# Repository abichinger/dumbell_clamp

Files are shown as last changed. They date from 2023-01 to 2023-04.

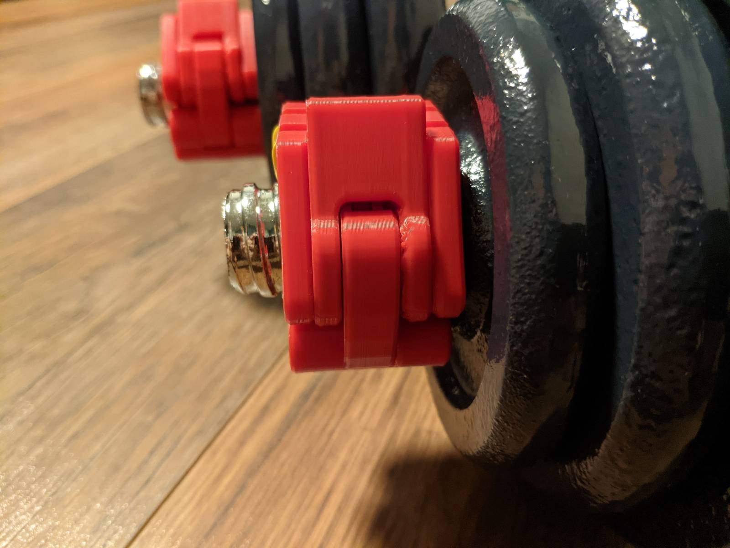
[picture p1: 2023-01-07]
assets/signal-2023-01-07-223349_003.jpeg

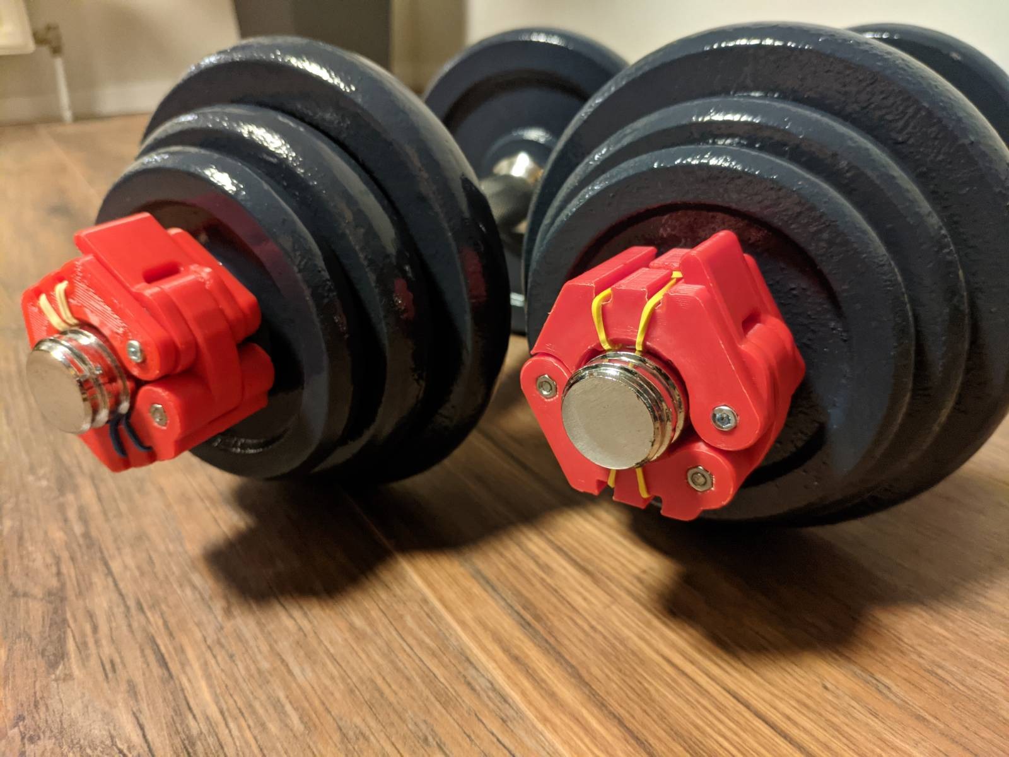
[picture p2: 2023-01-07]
assets/signal-2023-01-07-223349_005.jpeg

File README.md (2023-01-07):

**A customizable clamp to secure your weights on your dumbell or barbell.**

Choose between **25mm, 30mm, 50mm** or open up the Customizer and set a **custom diameter** with `Bar_Diameter`.
The grooves allow you to add **rubber bands** for optimal grip. If the clamp is too loose, you can add more rubber bands or increase the `Compression` parameter.

Required bolts (`Height` parameter set to 33mm):
- 2x M3x30mm
- 2x M3x8mm
- 1x M3x18mm
- 5x M3 hex nut

If you prefer to use pins, you can set the parameter `Hinge_Type` to `Pin`.

**Disclaimer**: I only printed the clamp with a diameter of 25mm. I hope the other versions work as well.

If you have some suggestion or need help, please open an issue at the [GitHub repository](https://github.com/abichinger/dumbell_clamp)

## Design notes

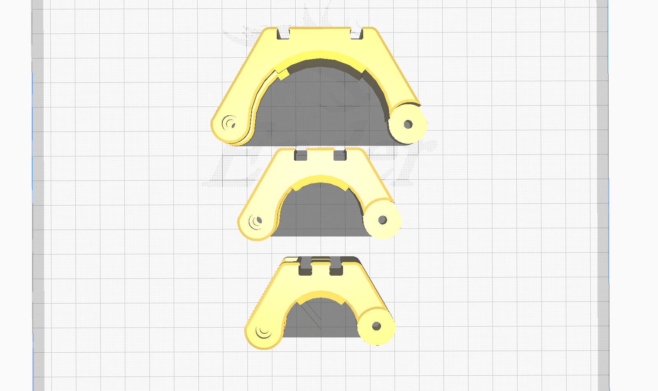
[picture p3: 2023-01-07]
assets/sizes.png

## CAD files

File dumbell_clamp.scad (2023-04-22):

Part_Selection = 0; // [0:Clamp, 1:Top, 2:Bottom, 3:Latch_Part1, 4:Latch_Part2, 5:None]
Bar_Diameter = 25;
Compression = 0.7;
Joint_Diameter = 15;
Bumper_Height = 1.5;
Bumper_Angle = 80;
Lever_Hole_Dist = 7.5;
Lever_Overhang = 9;

Height = 33;

Edge_Height = 1;
Edge_Radius = 7;

Bolt_Size = 0; // [0:M3, 1:M4, 2:M5]
Hinge_Type = 0; // [0:Bolt, 1:Pin]

Groove_Width = 5;
Groove_Height = 5;
Groove_Offset = -2;
Groove_Count = 1;

Grooves = true;
Bridges = false;
Cut_in_Half = false;
Second_Half = false;

/* [Hidden] */

od = Bar_Diameter+2*Joint_Diameter+2*Bumper_Height;
id = Bar_Diameter+2*Bumper_Height;
bar_d = Bar_Diameter - Compression;
bar_r = bar_d/2;
sub_h = Height/3;
alpha = (180-Bumper_Angle)/2;
joint_t = 0.8;
jd = Joint_Diameter + joint_t;
t = 0.25;
w = (od/2)*cos(30)*2;

Joint_Radius = Joint_Diameter/2;
jr = id/2+Joint_Radius;

//Kosinussatz https://de.wikipedia.org/wiki/Kosinussatz
function law_of_cos(a, b, gamma) = sqrt(a*a+b*b-2*a*b*cos(gamma));
function law_of_acos(a, b, c) = acos((a*a+b*b-c*c)/(2*a*b));
beta = law_of_acos(id/2+Joint_Radius, id/2+Joint_Radius, Joint_Diameter);
echo("beta", beta);

groove_dist = law_of_cos(bar_r, bar_r, Bumper_Angle);

$fn=30;

// Gewindedurchmesser, Schraubenkopfdurchmesser, Schraubenkopfhöhe
bolt_specs = [
    [3, 5.5, 3],
    [4, 7, 4],
    [5, 8.5, 5]
];
bolt_spec_t = [0.4, 0.7, 0.2];

// width across flats, thickness
nut_specs = [
    [5.5, 2.4],
    [7, 3.2],
    [8, 4.7]
];
nut_spec_t = [0.4, 0.3];

bolt_spec = bolt_specs[Bolt_Size];
nut_spec = nut_specs[Bolt_Size];

hinge_d = (Hinge_Type == 0) ? bolt_spec[0] + bolt_spec_t[0] : bolt_spec[0] + 0.1;
bolt_head_d = bolt_spec[1] + bolt_spec_t[1];
bolt_head_h = bolt_spec[2] + bolt_spec_t[2];
nut_w = nut_spec[0] + nut_spec_t[0];
nut_h = nut_spec[1] + nut_spec_t[1];

gamma = law_of_acos(id/2+Joint_Radius, id/2+Joint_Radius, Lever_Hole_Dist);
Latch_Angle = beta+gamma;

module hinge_base(Height=Height) {
    cylinder(d=hinge_d, h=Height);
}

//hinge_cut();

module hinge_cut(Height=Height) {

    layer_h = 0.2;

    if(Hinge_Type == 0) { //Bolt
        rotate(30)
        nut(nut_w, nut_h);

        if (Bridges) {
            hinge_h = Height-bolt_head_h-nut_h-2*layer_h;
            translate([0,0,nut_h+layer_h])
            hinge_base(hinge_h);
        }
        else {
            hinge_base();
        }

        translate([0,0,Height-bolt_head_h])
        cylinder(d=bolt_head_d, h=bolt_head_h);

        
    } else {
        hinge_base();
    }
}

module nut(w, h){
    $fn = 6;
    r = w/sqrt(3);
    cylinder(r=r, h=h);
}

module hexagon(d, h, e=Edge_Height) {
    r = d/2 - Edge_Radius/2;

    hull(){
        for(i = [0:5]){
            rotate([0,0,60*i])
            translate([r, 0])
            pillar(Edge_Radius, Edge_Radius-2*Edge_Height, h, Edge_Height);
        }
    }
}

//hexagon(od, Height);

module cone(d1, d2, h, angle=360) {
    r1 = d1/2;
    r2 = d2/2;
    
    rotate_extrude(angle=angle, convexity=10)
    polygon([
        [0,0],
        [r1, 0],
        [r2, h],
        [0, h]
    ]);
}

module rcube(size, e=-Edge_Height, r=Edge_Radius) {
    d = 2*r;
    s = [size[0]-d, size[1]-d, size[2]];

    translate([r,r])
    union(){
        long_pillar(d, d+2*e, s[2], abs(e), s[0]);
    
        translate([0, s[1]])
        long_pillar(d, d+2*e, s[2], abs(e), s[0]);
        
        rotate([-90,0,0])
        linear_extrude(s[1])
        projection()
        rotate([90,0,0])
        long_pillar(d, d+2*e, s[2], abs(e), s[0]);
    }
    
    
}

module pillar(d, base_d, h, base_h, angle=360) {
    cone(base_d, d, base_h, angle);
    translate([0, 0, base_h])
    cone(d, d, h-2*base_h, angle);
    translate([0, 0, h-base_h])
    cone(d, base_d, base_h, angle);
}

module long_pillar(d, base_d, h, base_h, l){
    
    pillar(d, base_d, h, base_h);
    translate([l,0])
    pillar(d, base_d, h, base_h);

    translate([l,0])
    rotate([0,-90,0])
    linear_extrude(l)
    projection()
    rotate([0,90,0])
    pillar(d, base_d, h, base_h);
    
}

function reverse(vec) = [for(i = [len(vec)-1:-1:0]) vec[i]];

function sum(vec, i=0) = vec[i] + 
    (i < len(vec)-1 ? sum(vec, i+1) : 0);

module pillar2(d, h, angle=360) {

    rh = reverse(h);

    for(i = [0:len(d)-2]) {
        z = (i > 0) ? sum(rh, len(rh)-i) : 0;
        translate([0, 0, z])
        cone(d[i], d[i+1], h[i], angle);
    }
}

module part_base(h) {

    difference(){
        union() {
            difference(){
                hexagon(od, h);

                translate([-od/2, -od/2, 0])
                cube([od, od/2, h]);
            }

            translate([id/2+Joint_Diameter/2,0])
            rotate([0,0,180])
            pillar(Joint_Diameter, Joint_Diameter-2*Edge_Height, h, Edge_Height, angle=180);

            translate([-id/2-Joint_Diameter/2,0])
            rotate([0,0,180])
            pillar(Joint_Diameter, Joint_Diameter-2*Edge_Height, h, Edge_Height, angle=180);
        }
        union() {
            pillar(id, id+2*Edge_Height, h, Edge_Height, angle=alpha+0.01);

            rotate([0,0,180-alpha])
            pillar(id, id+2*Edge_Height, h, Edge_Height, angle=alpha+0.01);

            rotate([0,0,alpha-1])
            pillar(bar_d, id+2*Edge_Height, h, 2*Edge_Height, angle=Bumper_Angle+2);
        }
    }
}

// part_base(Height);

module top() {

    module cut() {
        cone(od+10, od+10, Height, 90);
    }

    module cut2() {
        rotate(120)
        cone(od+10, od+10, Height, 180);
    }

    difference(){
        part_base(Height);
    
        translate([-id/2-Joint_Diameter/2, 0, sub_h-t])
        cylinder(d=jd, h=sub_h+2*t);

        rotate(-30)
        cut();

        cut2();

        rotate(beta)
        translate([id/2+Joint_Diameter/2, 0, sub_h])
        cylinder(d=jd, h=sub_h);
    }

    difference(){
        union(){
            rotate(beta)
            translate([id/2+Joint_Diameter/2,0])
            rotate([0,0,180])
            pillar(Joint_Diameter, Joint_Diameter-2*Edge_Height, Height, Edge_Height);

            intersection() {
                part_base(Height);
                
                rotate(beta)
                cone(od+10, od+10, Height, 60-beta);
            }
        }

        rotate(beta)
        translate([id/2+Joint_Diameter/2, 0, sub_h])
        cylinder(d=jd, h=sub_h);
    }

    intersection(){
        union(){
            part_base(sub_h-t);

            translate([0,0,Height-sub_h+t])
            part_base(sub_h-t);
        }
        
        cut2();
    }

}

module top_part() {
    difference(){
        top();
        
        translate([-jr, 0])
        hinge_cut();

        rotate(beta)
        translate([+jr, 0])
        rotate(-beta)
        hinge_cut();

        if (Grooves) {
            translate([0, w/2+0.5, 0])
            groove_cuts();
        }

        if (Cut_in_Half) {
            translate([0,0, Second_Half ? 0 : Height/2])
            cylinder(d=od+10,h=Height/2);
        }
    }
}

module bottom() {

    lever_w = (w-id)/2;

    module cut() {
        rotate(120)
        cone(od+10, od+10, Height, 180);
    }

    difference(){
        part_base(Height);

        translate([jr, 0, 0])
        pillar2([jd+2*Edge_Height, jd, jd], [Edge_Height, sub_h-Edge_Height]);

        translate([jr, 0, Height-sub_h])
        pillar2([jd, jd, jd+2*Edge_Height], [sub_h-Edge_Height, Edge_Height]);

        rotate(60)
        translate([-od/4,w/2-lever_w/2+Edge_Height,sub_h/2])
        lever(Height-sub_h, e=0);

        cut();
    }

    intersection(){
        union(){
            part_base(sub_h/2);

            translate([0,0,Height-sub_h/2])
            part_base(sub_h/2);
        }
        
        cut();
    }
}

module bottom_part() {
    difference() {
        bottom();

        translate([+jr, 0])
        hinge_cut();

        translate([-jr, 0])
        union() {
            cylinder(d=bolt_head_d, h=bolt_head_h);

            hinge_base();

            translate([0,0,Height-bolt_head_h])
            cylinder(d=bolt_head_d, h=bolt_head_h);
        }

        if (Grooves) {
            translate([0, w/2+0.5, 0])
            groove_cuts();
        }

        if (Cut_in_Half) {
            translate([0,0, Second_Half ? 0 : Height/2])
            cylinder(d=od+10,h=Height/2);
        }
    }
}

module _latch_part1() {

    h = sub_h-2*t;

    intersection(){
        difference(){
            pillar(od, od-2*Edge_Height, h, Edge_Height);
            pillar(id, id+2*Edge_Height, sub_h, Edge_Height);
        }
        
        cone(od+10, od+10, sub_h, Latch_Angle);
    }

    translate([jr,0])
    pillar(Joint_Diameter, Joint_Diameter-2*Edge_Height, h, Edge_Height);

    rotate(Latch_Angle)
    translate([jr,0])
    pillar(Joint_Diameter, Joint_Diameter-2*Edge_Height, h, Edge_Height);
}

module latch_part1() {
    difference(){
        _latch_part1();
        
        translate([jr,0,0])
        hinge_base();
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

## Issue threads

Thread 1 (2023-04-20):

Non-manifold

ABrambleNinja, 2023-04-20:
Hi,
Firstly, thanks so much for making this project! I really like the design and I'm very impressed you made it in OpenSCAD.

When I render this in OpenSCAD, it complains that it is not manifold, and when I import it into PrusaSlicer, some things that should not be filled in are filled in, like some of the bolt holes.

Do you have some process you use to transform the solid into something your slicer works on, or is your slicer just able to handle the volume?

I tried looking into changing the model to not have overlapping faces because I think that is what results in the non-manifold-ness but it's hard for me to understand what's going on with everything.

Thanks!

abichinger, 2023-04-22:
Hello @ABrambleNinja,
I'm glad you like my design.

> Do you have some process you use to transform the solid into something your slicer works on, or is your slicer just able to handle the volume?

My Slicer ([UltiMaker Cura](https://ultimaker.com/software/ultimaker-cura)) was able to handle the .stl files without any problems.

I'm going to look if I can fix the model.

abichinger, 2023-04-22:
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
PrusaSlicer 2.5.2 seems to slice correctly, although it auto-repaired some errors.

abichinger, 2023-04-22:
I uodated the files on Thingiverse

ABrambleNinja, 2023-04-28:
Thanks so much for looking into this for me! I feel dumb that I didn't notice that parameter in the OpenSCAD file. That fixes this issue completely for me!

Just one other quick question: I was trying to read through the source code to figure out what length bolts I would need if I adjusted the Height parameter, but I was having trouble making sense of it. Is there some easy formula to determine what lengths I'd need if I reduced the Height?

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

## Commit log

2022-08-01 fix: top hinge, lever
    [dumbell_clamp.scad]
2023-01-07 feat: add grooves
    [dumbell_clamp.scad]
2023-01-07 fix: increase tolerances
    [dumbell_clamp.scad]
2023-01-07 fix(bottom): replace nut inset with bolt head
    [dumbell_clamp.scad]
2023-04-22 fix: disable bridges
    [dumbell_clamp.scad]
2023-04-22 fix: non manifold stl #1
    errors have been caused by a thin face in part_base
    [dumbell_clamp.scad]
